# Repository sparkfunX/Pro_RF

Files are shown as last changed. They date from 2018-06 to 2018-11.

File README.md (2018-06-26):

SparkFun ProRF with RFM69/RFM95 LoRa
========================================

SparkFun ProRF

[*SparkX ProRF (SPX-14785)*](https://www.sparkfun.com/products/14785)

The Pro RF is the mind meld of a Pro Micro and a long-range RFM95W LoRa®-enabled radio. What you get is a very compact, easy to use Arduino with excellent point to point data transmission in the 915MHz ISM band. The Pro RF comes with a LiPo connector, a on-board LiPo charger, and a slide switch for On/Off. The board programs over a reinforced microB connector with a sleek reset button that fits nicely on the side of the board. We've even added our popular [Qwiic connector](https://www.sparkfun.com/qwiic) to the edge of the board making it incredibly fast to add sensors and actuators.

Thanks to the [Arduino LoRa library](https://github.com/sandeepmistry/arduino-LoRa), the RFM95W radio is an easy to use packet radio. But it doesn't stop at point-to-point packet radio because closing a few jumpers will give the Pro RF access to the DIO pins on the RFM95W which are necessary to operate in LoRaWAN mode, so you can use the Pro RF as a LoRaWAN node in a distributed sensor network such as [The Things Network](https://www.thethingsnetwork.org/).

The Pro RF also includes a power switch and 2-pin JST connector for powering from a lithium battery. With the power switch in the off position, the Pro RF will even charge the attached battery! 

And stop running out of ground pins! Every pin on the Pro RF is accompanied with a ground connection making buttons and LEDs super easy to connect. And in case your building something to be embedded into clothing or other physically harsh environment the antenna includes a stress relief hole to make sure your wire antenna survives.

Although a short (3 inch) wire antenna is sufficient for short distances (up to 1 mile line-of-sight), LoRa® is theoretically capable of covering extremely long distances (several miles) using the proper antenna. We've included the sketches we used for [range testing](https://cdn.sparkfun.com/assets/7/d/b/4/f/ProRF_RFM95.zip).

Checkout the [Pro Micro hookup guide](https://learn.sparkfun.com/tutorials/pro-micro--fio-v3-hookup-guide) as a general starting point for the Pro RF.

SparkFun labored with love to create this code. Feel like supporting open source hardware? 
Buy a [breakout board](https://www.sparkfun.com/products/14785) from SparkFun!

Repository Contents
-------------------

* **/Examples** - Example sketches showing how to setup the radio for maximuim range
* **/Hardware** - Eagle design files (.brd, .sch)

License Information
-------------------

This product is _**open source**_! 

If you have any questions or concerns on licensing, please contact techsupport@sparkfun.com.

Please use, reuse, and modify these files as you see fit. Please maintain attribution to SparkFun Electronics and release any derivative under the same license.

Distributed as-is; no warranty is given.

- Your friends at SparkFun.

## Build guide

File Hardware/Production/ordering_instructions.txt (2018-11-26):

panel size, 96x99mm
PCB thickness, 0.8mm
number of layers, 2
soldermask color, Red
silkscreen color, White
oz copper, 1oz
finish, HASL lead free
stencils, top
pcs per panel, 6

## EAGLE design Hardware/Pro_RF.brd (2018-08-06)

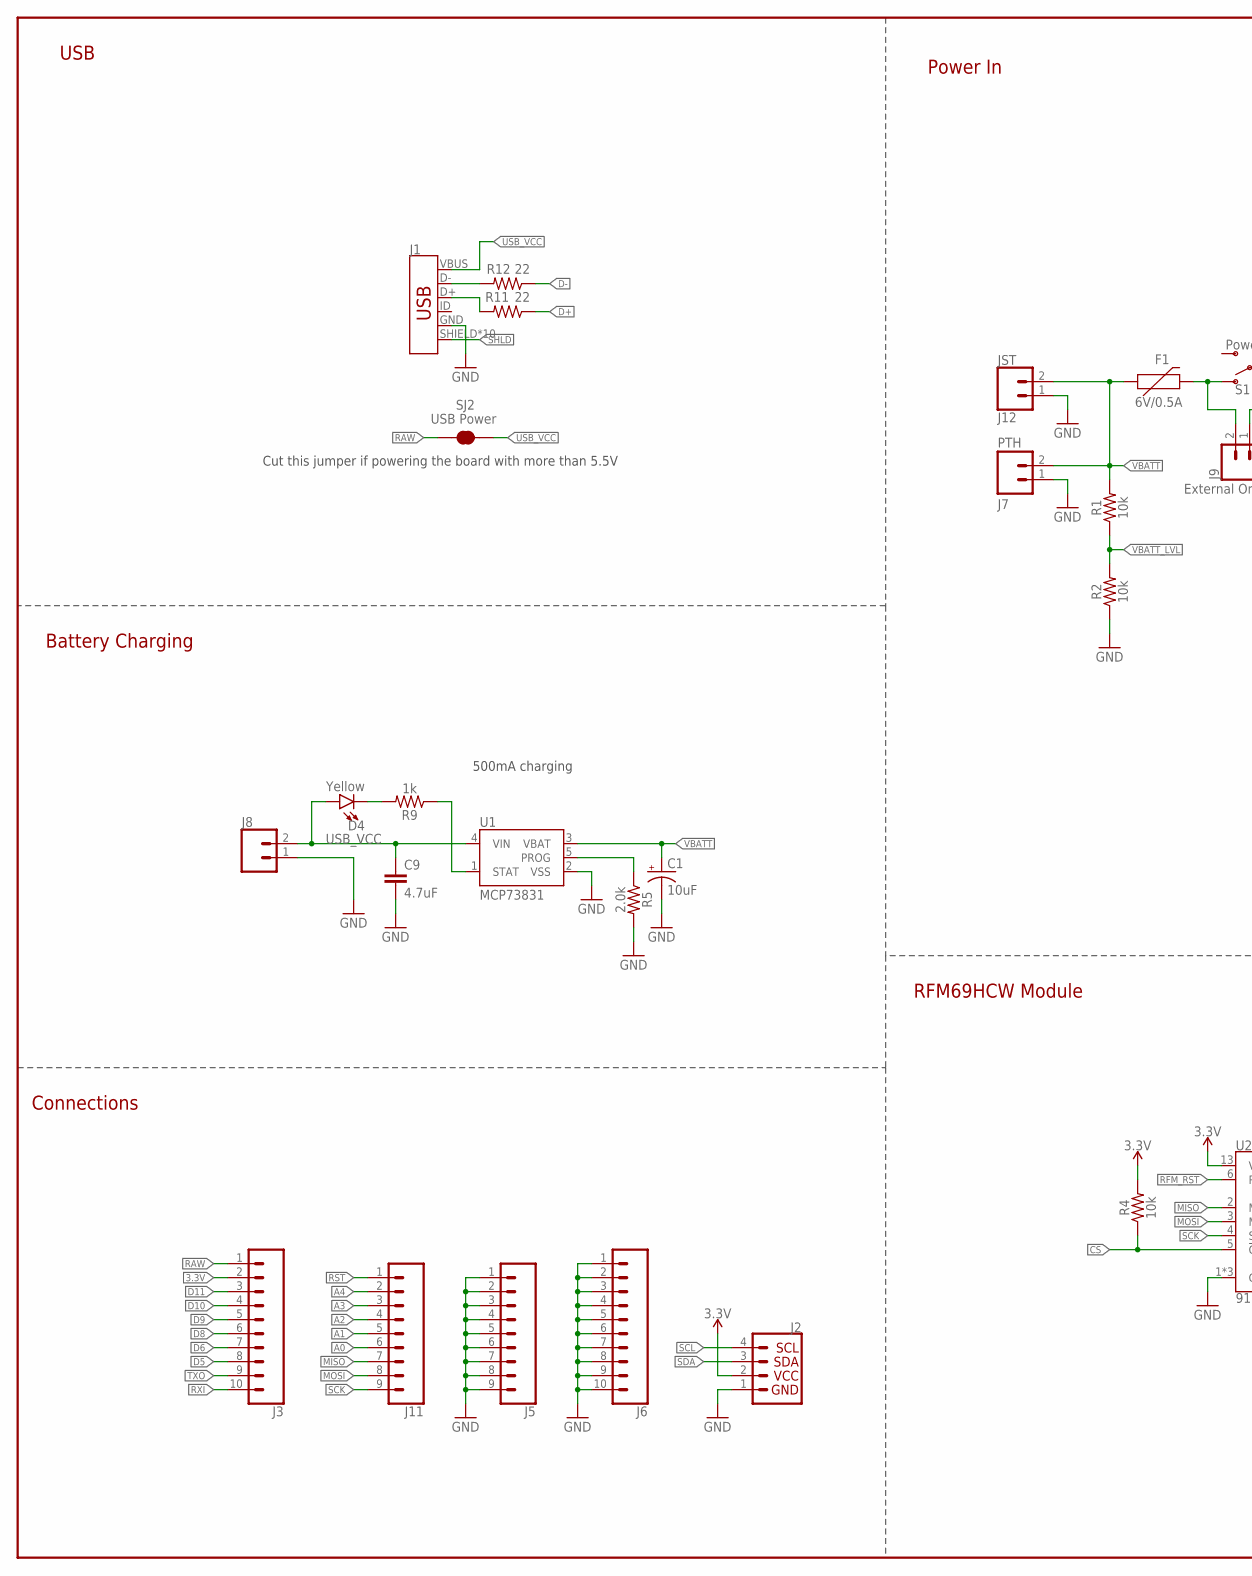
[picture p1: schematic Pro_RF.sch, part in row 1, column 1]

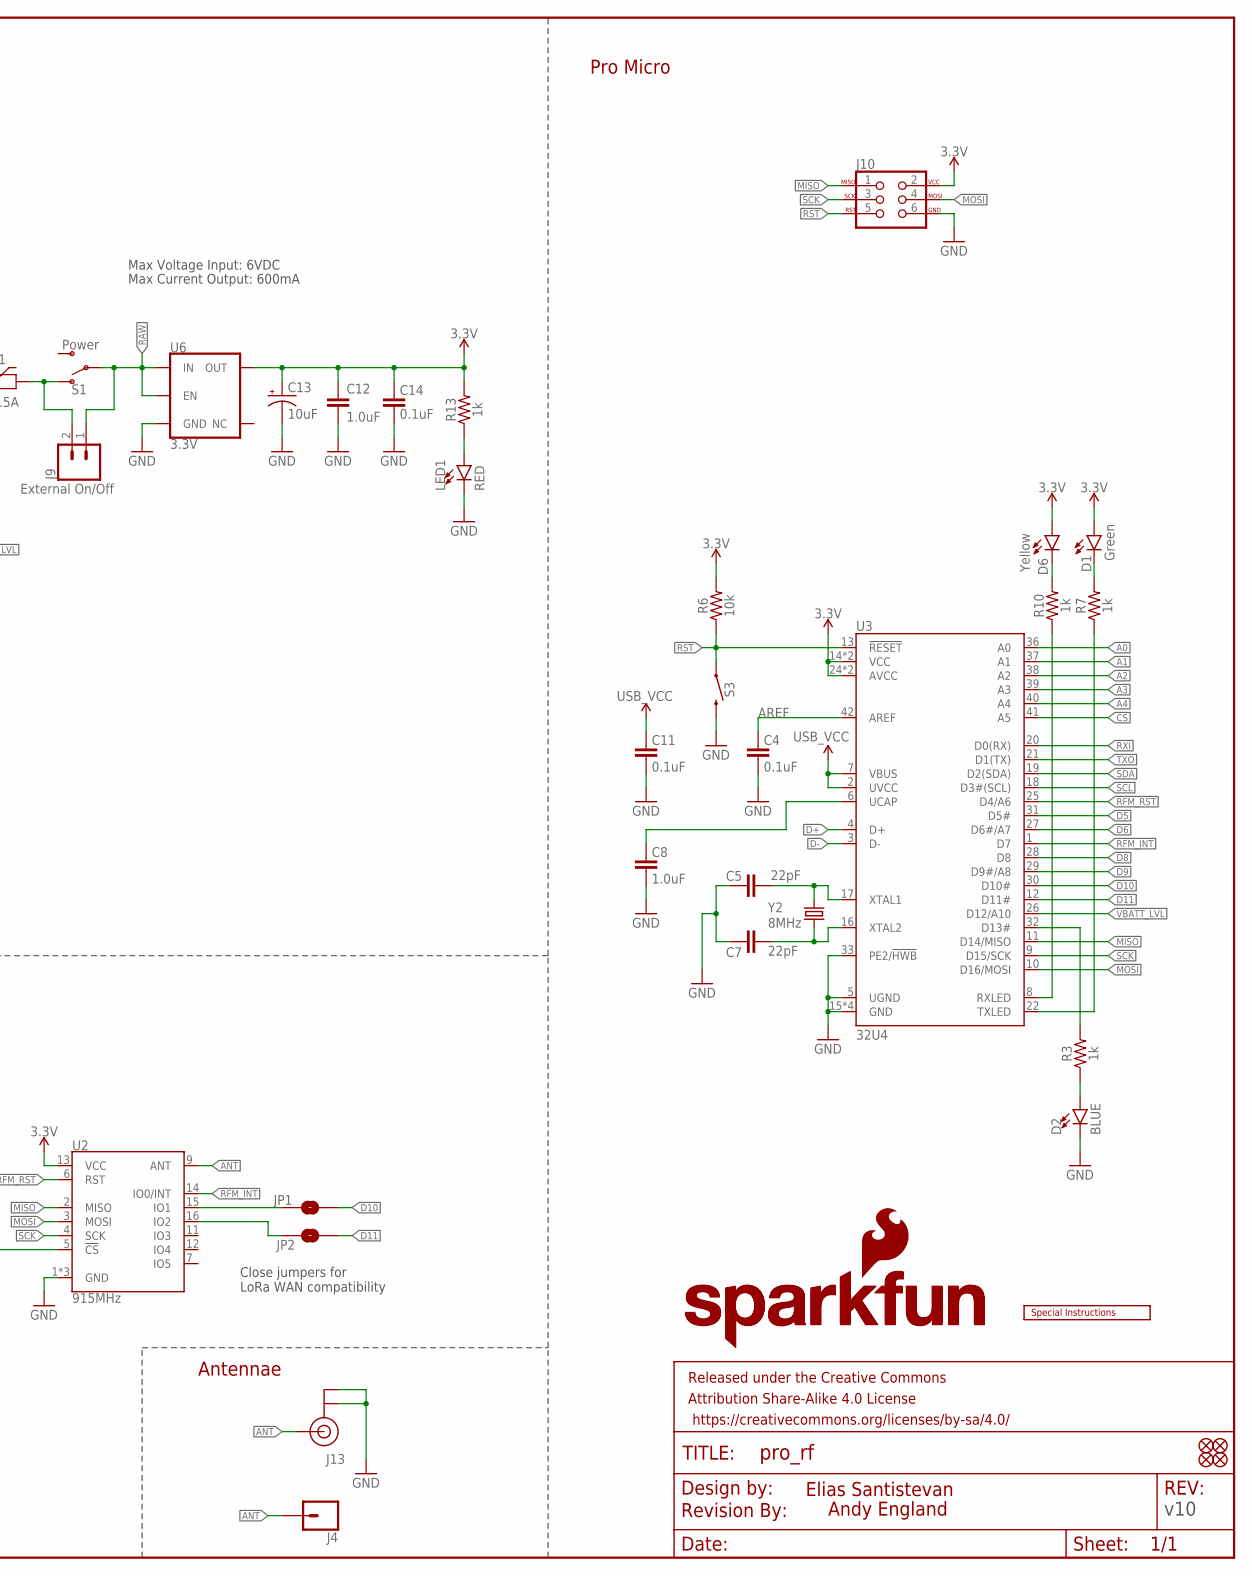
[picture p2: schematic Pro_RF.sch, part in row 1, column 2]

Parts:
C1, C13: 10uF; EIA3216
C4, C11, C14: 0.1uF; 0603
C5, C7: 22pF; 0603
C8, C12: 1.0uF; 0603
C9: 4.7uF; 0603
D1: Green; LED-0603
D2: BLUE; LED-0603
D4, D6: Yellow; LED-0603
F1: 6V/0.5A; 1206
FD1, FD2, FD3, FD4: FIDUCIAL1X2; FIDUCIAL-1X2
FRAME2: FRAME-LEDGER; CREATIVE_COMMONS
J1: USB_MICRO-B_HALF_PTH_MILL; USB-MICROB-PTH-MILL
J2: QWIIC_CONNECTORJS-1MM; 1X04_1MM_RA
J3, J6: CONN_10NO_SILK_PTH_FEMALE; 1X10_NO_SILK
J4: CONN_01PTH_NO_SILK_YES_STOP; 1X01_NO_SILK
J5, J11: CONN_09NO_SILK; 1X09_NO_SILK
J7: PTH; 1X02_NO_SILK
J8: CONN_021X02_NO_SILK; 1X02_NO_SILK
J9: External On/Off; 1X02_NO_SILK
J10: AVR_SPI_PROG_3X2TESTPOINTS; 2X3_TEST_POINTS
J12: JST; JST-2-SMD
J13: U.FL
JP1, JP2: JUMPER-SMT_2_NO_SILK; SMT-JUMPER_2_NO_SILK
LED1: RED; LED-0603
LOGO1: REVISION
LOGO2: SFE_LOGO_NAME.1_INCH; SFE_LOGO_NAME_.1
LOGO3: SFE_LOGO_NAME_FLAME.1_INCH; SFE_LOGO_NAME_FLAME_.1
R1, R2, R4, R6: 10k; 0603
R3, R7, R9, R10, R13: 1k; 0603
R5: 2.0k; 0603
R11, R12: 22; 0603
S1: Power; SWITCH_SPST_SMD_A
S3: MOMENTARY-SWITCH-SPST-SMD-RIGHT-ANGLE; TACTILE_SWITCH_SMD_RIGHT_ANGLE
SJ2: USB Power; SMT-JUMPER_2_NC_TRACE_SILK
U1: MCP73831; SOT23-5
U2: 915MHz; RFM69HCW-XXXS2
U3: 32U4; QFN-44-NOPAD
U6: 3.3V; SOT23-5
U$26: SPECIAL_INSTRUCTIONS-ORDERING; ORDERING_INSTRUCTIONS
Y2: 8MHz; CRYSTAL-SMD-5X3.2-4PAD

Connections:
3.3V: C12.1, C13.+, C14.2, D1.A, D6.A, J2.2, J3.2, J10.2, R4.2, R6.2, R13.2, U2.13 (VCC), U3.14 (VCC), U3.24 (AVCC), U3.34 (VCC), U3.44 (AVCC), U6.5 (OUT)
!CS: R4.1, U2.5 (!CS), U3.41 (A5)
!RST: J10.5, J11.1, R6.1, S3.1, U3.13 (!RESET)
A0: J11.6, U3.36 (A0)
A1: J11.5, U3.37 (A1)
A2: J11.4, U3.38 (A2)
A3: J11.3, U3.39 (A3)
A4: J11.2, U3.40 (A4)
ANT: J4.1, J13.FEED (SIGNAL), U2.9 (ANT)
AREF: C4.2, U3.42 (AREF)
CHARGE_STAT: R9.1, U1.1 (STAT)
D5: J3.8, U3.31 (D5#)
D6: J3.7, U3.27 (D6#/A7)
D8: J3.6, U3.28 (D8)
D9: J3.5, U3.29 (D9#/A8)
D10: J3.4, JP1.2, U3.30 (D10#)
D11: J3.3, JP2.2, U3.12 (D11#)
D+: R11.1, U3.4 (D+)
D-: R12.1, U3.3 (D-)
GND: C1.-, C4.1, C5.2, C7.2, C8.1, C9.2, C11.1, C12.2, C13.-, C14.1, D2.C, J1.GND, J2.1, J5.1, J5.2, J5.3, J5.4, J5.5, J5.6, J5.7, J5.8, J5.9, J6.1, J6.2, J6.3, J6.4, J6.5, J6.6, J6.7, J6.8, J6.9, J6.10, J7.1, J8.1, J10.6, J12.1 (2), J13.1 (GND), J13.2 (GND), LED1.C, R2.1, R5.2, S3.2, U1.2 (VSS), U2.1 (GND), U2.8 (GND), U2.10 (GND), U3.5 (UGND), U3.15 (GND), U3.23 (GND), U3.33 (PE2/!HWB), U3.35 (GND), U3.43 (GND), U6.2 (GND)
MISO: J10.1, J11.7, U2.2 (MISO), U3.11 (D14/MISO)
MOSI: J10.4, J11.8, U2.3 (MOSI), U3.10 (D16/MOSI)
unnamed: D6.C, R10.2
unnamed: D1.C, R7.2
unnamed: D2.A, R3.1
unnamed: C5.1, U3.17 (XTAL1), Y2.3 (2)
unnamed: J1.D+, R11.2
unnamed: C7.1, U3.16 (XTAL2), Y2.1
unnamed: D4.C, R9.2
unnamed: F1.2, J9.2, S1.1 (O)
unnamed: R5.1, U1.5 (PROG)
unnamed: J1.D-, R12.2
unnamed: LED1.A, R13.1
RAW: J3.1, J9.1, S1.2, SJ2.1, U6.1 (IN), U6.3 (EN)
RFM_INT: U2.14 (IO0/INT), U3.1 (D7)
RFM_IO1: JP1.1, U2.15 (IO1)
RFM_IO2: JP2.1, U2.16 (IO2)
RFM_RST: U2.6 (RST), U3.25 (D4/A6)
RXI: J3.10, U3.20 (D0(RX))
RXLED: R10.1, U3.8 (RXLED)
SCK: J10.3, J11.9, U2.4 (SCK), U3.9 (D15/SCK)
SCL: J2.4, U3.18 (D3#(SCL))
SDA: J2.3, U3.19 (D2(SDA))
SHLD: J1.SHIELD, J1.SHIELD2 (SHIELD), J1.SHIELD3 (SHIELD), J1.SHIELD4 (SHIELD), J1.SHIELD5 (SHIELD), J1.SHIELD6 (SHIELD), J1.SHIELD7 (SHIELD), J1.SHIELD8 (SHIELD), J1.SHIELD9 (SHIELD), J1.SHIELD10 (SHIELD)
STAT: R3.2, U3.32 (D13#)
TXLED: R7.1, U3.22 (TXLED)
TXO: J3.9, U3.21 (D1(TX))
UCAP: C8.2, U3.6 (UCAP)
USB_VCC: C9.1, C11.2, D4.A, J1.VBUS, J8.2, SJ2.2, U1.4 (VIN), U3.2 (UVCC), U3.7 (VBUS)
VBATT: C1.+, F1.1, J7.2, J12.2 (1), R1.2, U1.3 (VBAT)
VBATT_LVL: R1.1, R2.2, U3.26 (D12/A10)

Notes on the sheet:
Max Voltage Input: 6VDC
Max Current Output: 600mA
Cut this jumper if powering the board with more than 5.5V
500mA charging
Close jumpers for LoRa WAN compatibility
Battery Charging
Power In
Pro Micro
RFM69HCW Module
v10
Andy England
Connections
Elias Santistevan
USB
Antennae

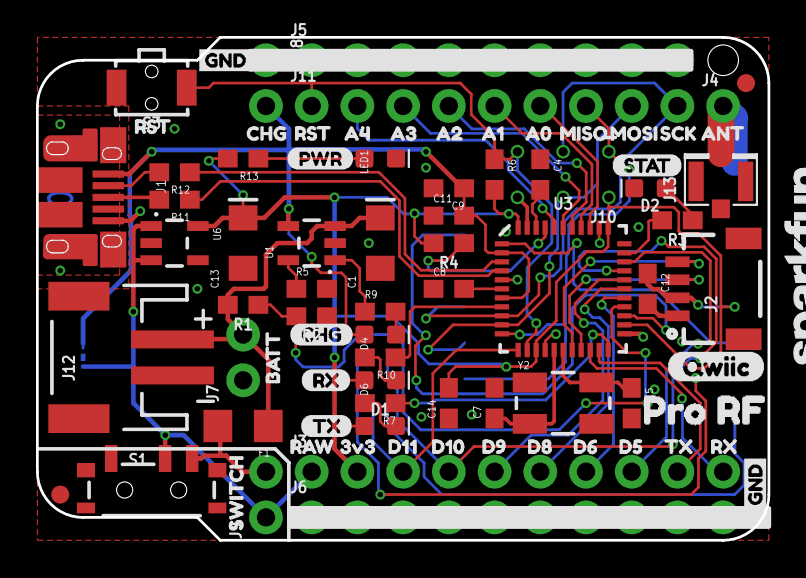
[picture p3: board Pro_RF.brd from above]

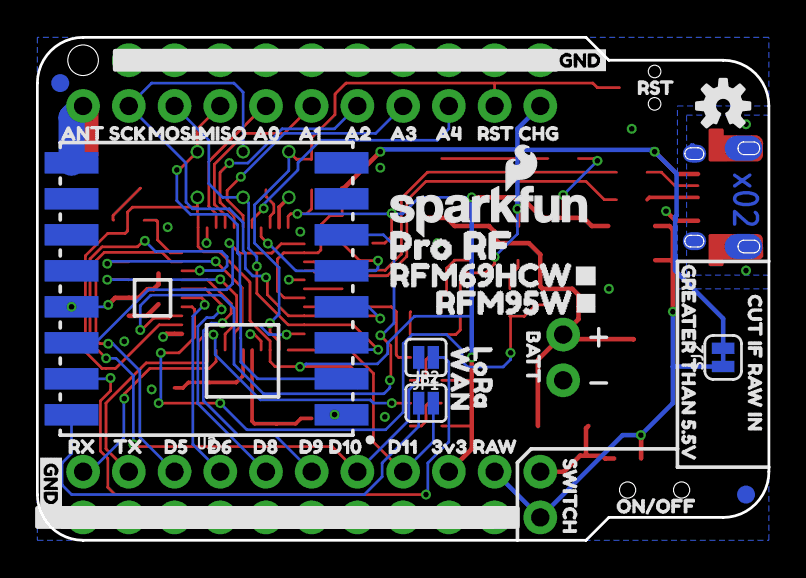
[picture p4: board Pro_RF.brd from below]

Board: 2 copper layers, 40.6 x 27.9 mm, 128 parts (42 on the bottom side), 51 nets.

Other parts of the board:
U$1, U$31: PRO_RF0
U$3, U$42: A43
U$4, U$43: A34
U$5, U$44: A25
U$6, U$45: A16
U$7, U$46: A07
U$8, U$47: MISO8
U$9, U$48: MOSI9
U$10, U$49: SCK10
U$11, U$50: ANT11
U$12, U$17, U$38, U$62: GND0
U$13, U$28, U$36, U$41: RST2
U$14, U$40, U$65: CHG1
U$15, U$16: D90
U$18, U$58: D615
U$19, U$73: RX2
U$20, U$56: D817
U$21, U$68: D100
U$22, U$54: D1119
U$23, U$53: 3V320
U$24, U$52: RAW21
U$25: LORA0
U$27, U$37: SWITCH23
U$29, U$32: BATT25
U$33: CUT_IF_RAW_IN0
U$34: GREATER_THAN_5#5V1
U$35: WAN1
U$39: ON#OFF0
U$51: OSHW-LOGO-S
U$55, U$74: D514
U$57, U$69: TX3
U$59: RFM69HCW#1
U$60: RFM95W#0
U$63: PWR-()-03
U$66: QWIIC-()-04
U$70: TX6
U$71: STAT5
U$72: RX7

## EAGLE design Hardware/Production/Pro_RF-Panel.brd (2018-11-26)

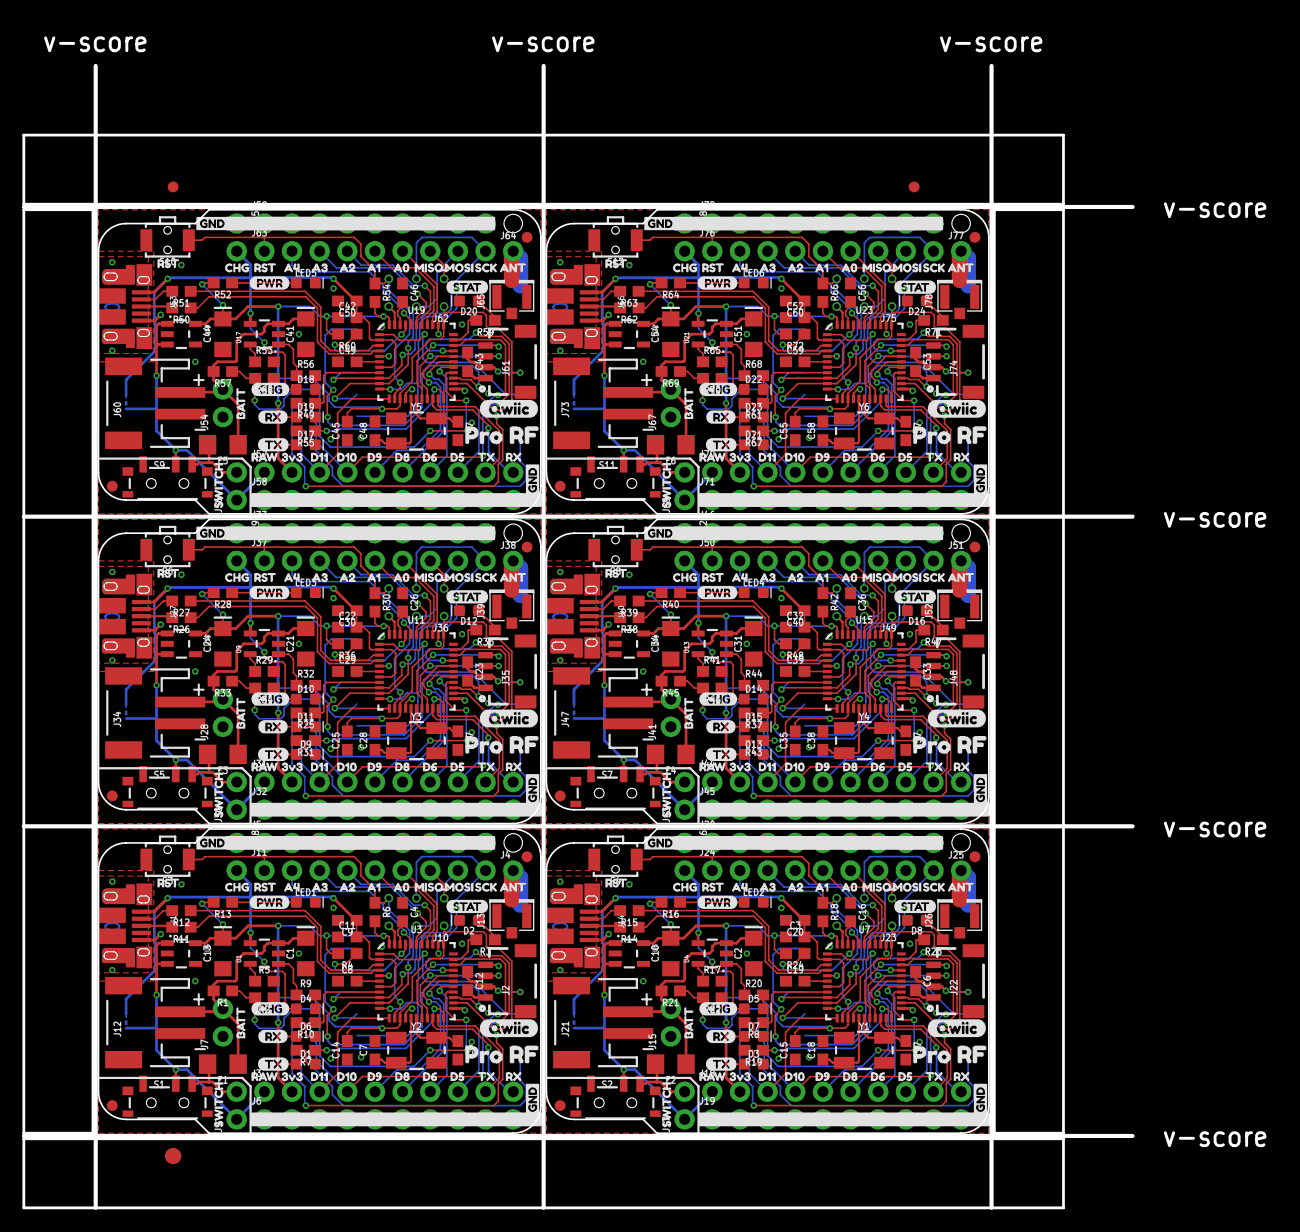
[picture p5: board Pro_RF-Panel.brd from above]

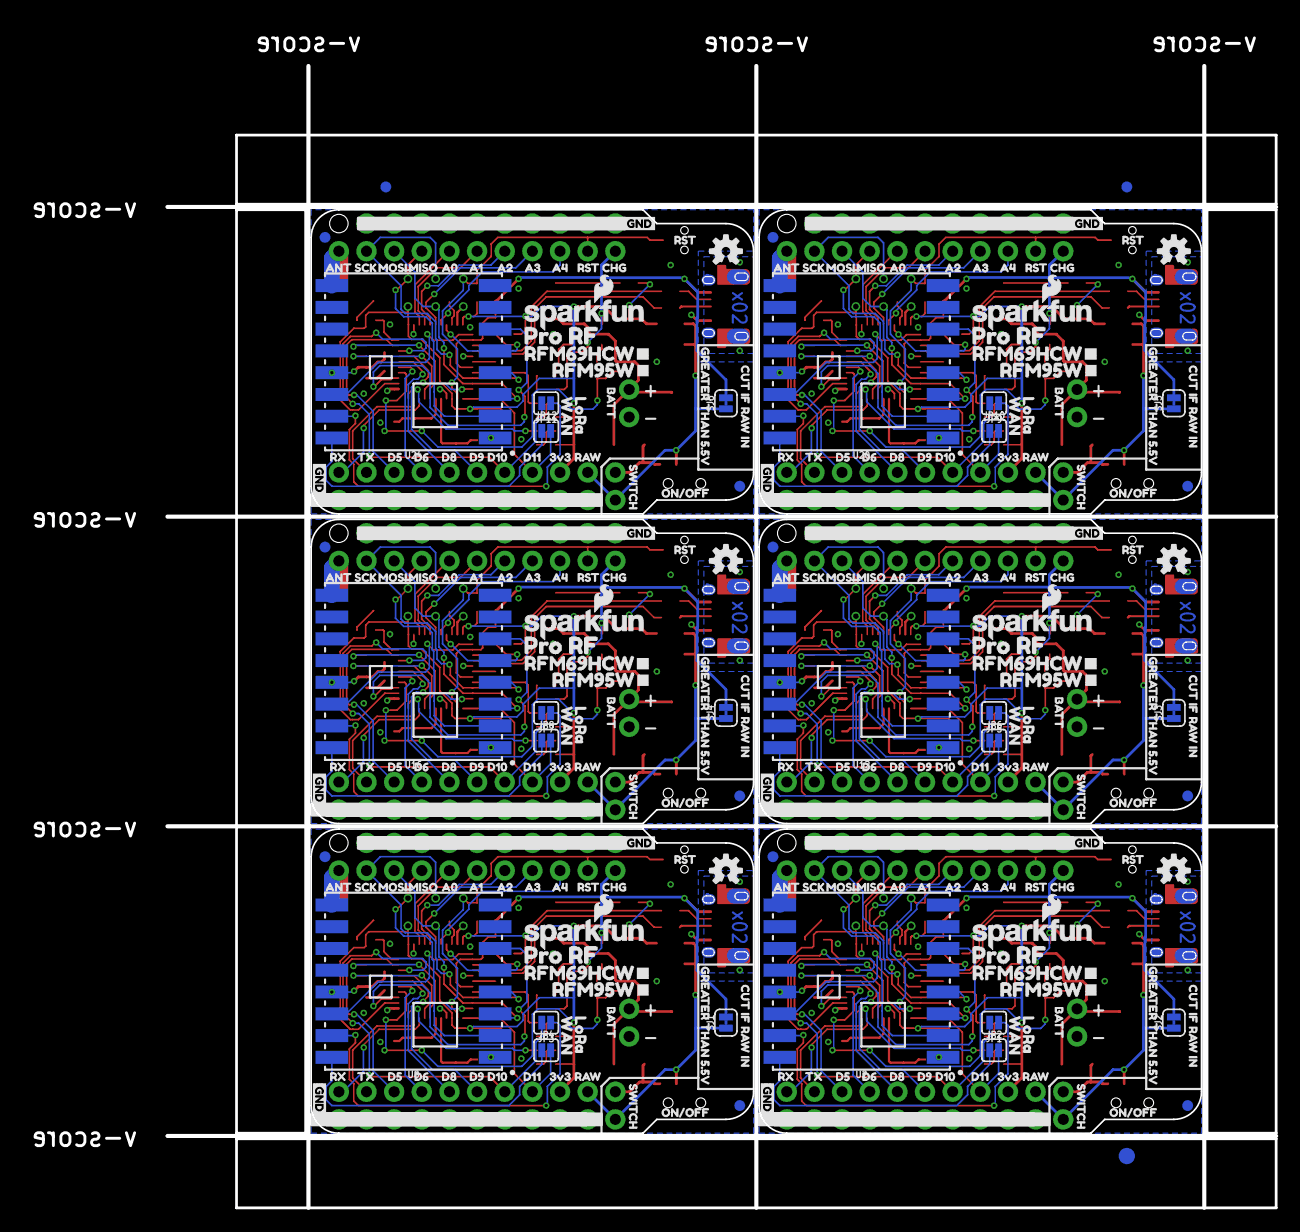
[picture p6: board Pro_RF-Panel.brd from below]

Board: 2 copper layers, 101.9 x 104.9 mm, 750 parts (255 on the bottom side), 306 nets.

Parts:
C1, C2, C10, C13, C21, C24, C31, C34, C41, C44, C51, C54: 10uF; EIA3216
C3, C4, C11, C14, C15, C16, C22, C25, C26, C32, C35, C36, C42, C45, C46, C52, C55, C56: 0.1uF; 0603
C5, C7, C17, C18, C27, C28, C37, C38, C47, C48, C57, C58: 22pF; 0603
C6, C8, C12, C19, C23, C29, C33, C39, C43, C49, C53, C59: 1.0uF; 0603
C9, C20, C30, C40, C50, C60: 4.7uF; 0603
D1, D3, D9, D13, D17, D21: Green; LED-0603
D2, D8, D12, D16, D20, D24: BLUE; LED-0603
D4, D5, D6, D7, D10, D11, D14, D15, D18, D19, D22, D23: Yellow; LED-0603
E$1, E$2, E$3, E$4: FIDUCIAL-1X2
E$5, E$6: FIDUCIAL-1.5X3
F1, F2, F3, F4, F5, F6: 6V/0.5A; 1206
FD1, FD2, FD3, FD4, FD5, FD6, FD7, FD8, FD9, FD10, FD11, FD12, FD13, FD14, FD15, FD16, FD17, FD18, FD19, FD20, FD21, FD22, FD23, FD24: FIDUCIAL1X2; FIDUCIAL-1X2
J1, J14, J27, J40, J53, J66: USB-MICROB-PTH-MILL
J2, J22, J35, J48, J61, J74: 1X04_1MM_RA
J3, J6, J18, J19, J31, J32, J44, J45, J57, J58, J70, J71: 1X10_NO_SILK
J4, J25, J38, J51, J64, J77: 1X01_NO_SILK
J5, J11, J20, J24, J33, J37, J46, J50, J59, J63, J72, J76: 1X09_NO_SILK
J7, J15, J28, J41, J54, J67: PTH; 1X02_NO_SILK
J8, J16, J29, J42, J55, J68: 1X02_NO_SILK
J9, J17, J30, J43, J56, J69: External On/Off; 1X02_NO_SILK
J10, J23, J36, J49, J62, J75: AVR_SPI_PROG_3X2TESTPOINTS; 2X3_TEST_POINTS
J12, J21, J34, J47, J60, J73: JST; JST-2-SMD
J13, J26, J39, J52, J65, J78: U.FL
JP1, JP2, JP3, JP4, JP5, JP6, JP7, JP8, JP9, JP10, JP11, JP12: SMT-JUMPER_2_NO_SILK
LED1, LED2, LED3, LED4, LED5, LED6: RED; LED-0603
LOGO1, LOGO2, LOGO3, LOGO4, LOGO5, LOGO6: SFE_LOGO_NAME_FLAME.1_INCH; SFE_LOGO_NAME_FLAME_.1
R1, R2, R4, R6, R18, R21, R22, R24, R30, R33, R34, R36, R42, R45, R46, R48, R54, R57, R58, R60, R66, R69, R70, R72: 10k; 0603
R3, R7, R8, R9, R10, R13, R16, R19, R20, R23, R25, R28, R31, R32, R35, R37, R40, R43, R44, R47, R49, R52, R55, R56, R59, R61, R64, R67, R68, R71: 1k; 0603
R5, R17, R29, R41, R53, R65: 2.0k; 0603
R11, R12, R14, R15, R26, R27, R38, R39, R50, R51, R62, R63: 22; 0603
S1, S2, S5, S7, S9, S11: Power; SWITCH_SPST_SMD_A
S3, S4, S6, S8, S10, S12: TACTILE_SWITCH_SMD_RIGHT_ANGLE
SJ1, SJ2, SJ3, SJ4, SJ5, SJ6: USB Power; SMT-JUMPER_2_NC_TRACE_SILK
U1, U4, U9, U13, U17, U21: MCP73831; SOT23-5
U2, U8, U12, U16, U20, U24: 915MHz; RFM69HCW-XXXS2
U3, U7, U11, U15, U19, U23: 32U4; QFN-44-NOPAD
U5, U6, U10, U14, U18, U22: 3.3V; SOT23-5
U$1, U$2, U$31, U$90, U$137, U$158, U$205, U$226, U$273, U$294, U$341, U$362: PRO_RF0
U$3, U$26, U$42, U$100, U$138, U$168, U$206, U$236, U$274, U$304, U$342, U$372: A43
U$4, U$30, U$43, U$101, U$139, U$169, U$207, U$237, U$275, U$305, U$343, U$373: A34
U$5, U$44, U$61, U$102, U$140, U$170, U$208, U$238, U$276, U$306, U$344, U$374: A25
U$6, U$45, U$64, U$103, U$141, U$171, U$209, U$239, U$277, U$307, U$345, U$375: A16
U$7, U$46, U$67, U$104, U$142, U$172, U$210, U$240, U$278, U$308, U$346, U$376: A07
U$8, U$47, U$75, U$105, U$143, U$173, U$211, U$241, U$279, U$309, U$347, U$377: MISO8
U$9, U$48, U$76, U$106, U$144, U$174, U$212, U$242, U$280, U$310, U$348, U$378: MOSI9
U$10, U$49, U$77, U$107, U$145, U$175, U$213, U$243, U$281, U$311, U$349, U$379: SCK10
U$11, U$50, U$78, U$108, U$146, U$176, U$214, U$244, U$282, U$312, U$350, U$380: ANT11
U$12, U$17, U$38, U$62, U$79, U$96, U$115, U$130, U$147, U$164, U$183, U$198, U$215, U$232, U$251, U$266, U$283, U$300, U$319, U$334, U$351, U$368, U$387, U$402: GND0
U$13, U$28, U$36, U$41, U$80, U$88, U$94, U$99, U$148, U$156, U$162, U$167, U$216, U$224, U$230, U$235, U$284, U$292, U$298, U$303, U$352, U$360, U$366, U$371: RST2
U$14, U$40, U$65, U$81, U$98, U$123, U$149, U$166, U$191, U$217, U$234, U$259, U$285, U$302, U$327, U$353, U$370, U$395: CHG1
U$15, U$16, U$128, U$129, U$196, U$197, U$264, U$265, U$332, U$333, U$400, U$401: D90
U$18, U$58, U$82, U$114, U$150, U$182, U$218, U$250, U$286, U$318, U$354, U$386: D615
U$19, U$73, U$122, U$131, U$190, U$199, U$258, U$267, U$326, U$335, U$394, U$403: RX2
U$20, U$56, U$83, U$113, U$151, U$181, U$219, U$249, U$287, U$317, U$355, U$385: D817
U$21, U$68, U$124, U$125, U$192, U$193, U$260, U$261, U$328, U$329, U$396, U$397: D100
U$22, U$54, U$84, U$112, U$152, U$180, U$220, U$248, U$288, U$316, U$356, U$384: D1119
U$23, U$53, U$85, U$111, U$153, U$179, U$221, U$247, U$289, U$315, U$357, U$383: 3V320
U$24, U$52, U$86, U$110, U$154, U$178, U$222, U$246, U$290, U$314, U$358, U$382: RAW21
U$25, U$135, U$203, U$271, U$339, U$407: LORA0
U$27, U$37, U$87, U$95, U$155, U$163, U$223, U$231, U$291, U$299, U$359, U$367: SWITCH23
U$29, U$32, U$89, U$91, U$157, U$159, U$225, U$227, U$293, U$295, U$361, U$363: BATT25
U$33, U$92, U$160, U$228, U$296, U$364: CUT_IF_RAW_IN0
U$34, U$93, U$161, U$229, U$297, U$365: GREATER_THAN_5#5V1
U$35, U$136, U$204, U$272, U$340, U$408: WAN1
U$39, U$97, U$165, U$233, U$301, U$369: ON#OFF0
U$51, U$109, U$177, U$245, U$313, U$381: OSHW-LOGO-S
U$55, U$74, U$126, U$127, U$194, U$195, U$262, U$263, U$330, U$331, U$398, U$399: D514
U$57, U$69, U$118, U$132, U$186, U$200, U$254, U$268, U$322, U$336, U$390, U$404: TX3
U$59, U$133, U$201, U$269, U$337, U$405: RFM69HCW#1
U$60, U$134, U$202, U$270, U$338, U$406: RFM95W#0
U$63, U$116, U$184, U$252, U$320, U$388: PWR-()-03
U$66, U$117, U$185, U$253, U$321, U$389: QWIIC-()-04
U$70, U$119, U$187, U$255, U$323, U$391: TX6
U$71, U$120, U$188, U$256, U$324, U$392: STAT5
U$72, U$121, U$189, U$257, U$325, U$393: RX7
Y1, Y2, Y3, Y4, Y5, Y6: 8MHz; CRYSTAL-SMD-5X3.2-4PAD

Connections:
3.3V: C12.1, C13.+, C14.2, D1.A, D6.A, J2.2, J3.2, J10.2, R4.2, R6.2, R13.2, U2.13, U3.14, U3.24, U3.34, U3.44, U6.5
3.3V1: C6.1, C10.+, C15.2, D3.A, D7.A, J18.2, J22.2, J23.2, R16.2, R18.2, R24.2, U5.5, U7.14, U7.24, U7.34, U7.44, U8.13
3.3V2: C23.1, C24.+, C25.2, D9.A, D11.A, J31.2, J35.2, J36.2, R28.2, R30.2, R36.2, U10.5, U11.14, U11.24, U11.34, U11.44, U12.13
3.3V3: C33.1, C34.+, C35.2, D13.A, D15.A, J44.2, J48.2, J49.2, R40.2, R42.2, R48.2, U14.5, U15.14, U15.24, U15.34, U15.44, U16.13
3.3V4: C43.1, C44.+, C45.2, D17.A, D19.A, J57.2, J61.2, J62.2, R52.2, R54.2, R60.2, U18.5, U19.14, U19.24, U19.34, U19.44, U20.13
3.3V5: C53.1, C54.+, C55.2, D21.A, D23.A, J70.2, J74.2, J75.2, R64.2, R66.2, R72.2, U22.5, U23.14, U23.24, U23.34, U23.44, U24.13
!CS: R4.1, U2.5, U3.41
!CS1: R24.1, U7.41, U8.5
!CS2: R36.1, U11.41, U12.5
!CS3: R48.1, U15.41, U16.5
!CS4: R60.1, U19.41, U20.5
!CS5: R72.1, U23.41, U24.5
!RST: J10.5, J11.1, R6.1, S3.1, U3.13
!RST1: J23.5, J24.1, R18.1, S4.1, U7.13
!RST2: J36.5, J37.1, R30.1, S6.1, U11.13
!RST3: J49.5, J50.1, R42.1, S8.1, U15.13
!RST4: J62.5, J63.1, R54.1, S10.1, U19.13
!RST5: J75.5, J76.1, R66.1, S12.1, U23.13
A0: J11.6, U3.36
A1: J11.5, U3.37
A2: J11.4, U3.38
A3: J11.3, U3.39
A4: J11.2, U3.40
A5: J24.6, U7.36
A6: J24.5, U7.37
A7: J24.4, U7.38
A8: J24.3, U7.39
A9: J24.2, U7.40
A10: J37.6, U11.36
A11: J37.5, U11.37
A12: J37.4, U11.38
A13: J37.3, U11.39
A14: J37.2, U11.40
A15: J50.6, U15.36
A16: J50.5, U15.37
A17: J50.4, U15.38
A18: J50.3, U15.39
A19: J50.2, U15.40
A20: J63.6, U19.36
A21: J63.5, U19.37
A22: J63.4, U19.38
A23: J63.3, U19.39
A24: J63.2, U19.40
A25: J76.6, U23.36
A26: J76.5, U23.37
A27: J76.4, U23.38
A28: J76.3, U23.39
A29: J76.2, U23.40
ANT: J4.1, J13.FEED, U2.9
ANT1: J25.1, J26.FEED, U8.9
ANT2: J38.1, J39.FEED, U12.9
ANT3: J51.1, J52.FEED, U16.9
ANT4: J64.1, J65.FEED, U20.9
ANT5: J77.1, J78.FEED, U24.9
AREF: C4.2, U3.42
AREF1: C16.2, U7.42
AREF2: C26.2, U11.42
AREF3: C36.2, U15.42
AREF4: C46.2, U19.42
AREF5: C56.2, U23.42
CHARGE_STAT: R9.1, U1.1
CHARGE_STAT1: R20.1, U4.1
CHARGE_STAT2: R32.1, U9.1
CHARGE_STAT3: R44.1, U13.1
CHARGE_STAT4: R56.1, U17.1
CHARGE_STAT5: R68.1, U21.1
D1: J18.8, U7.31
D2: J18.7, U7.27
D3: J18.6, U7.28
D4: J18.4, JP3.2, U7.30
D5: J3.8, U3.31
D6: J3.7, U3.27
D7: J18.5, U7.29
D8: J3.6, U3.28
D9: J3.5, U3.29
D10: J3.4, JP1.2, U3.30
D11: J3.3, JP2.2, U3.12
D12: J18.3, JP4.2, U7.12
D13: J31.8, U11.31
D14: J31.7, U11.27
D15: J31.6, U11.28
D16: J31.4, JP5.2, U11.30
D17: J31.5, U11.29
D18: J31.3, JP6.2, U11.12
D19: J44.8, U15.31
D20: J44.7, U15.27
D21: J44.6, U15.28
D22: J44.4, JP7.2, U15.30
D23: J44.5, U15.29
D24: J44.3, JP8.2, U15.12
D25: J57.8, U19.31
D26: J57.7, U19.27
D27: J57.6, U19.28
D28: J57.4, JP9.2, U19.30
D29: J57.5, U19.29
D30: J57.3, JP10.2, U19.12
D31: J70.8, U23.31
D32: J70.7, U23.27
D33: J70.6, U23.28
D34: J70.4, JP11.2, U23.30
D35: J70.5, U23.29
D36: J70.3, JP12.2, U23.12
D+: R11.1, U3.4
D+1: R14.1, U7.4
D+2: R26.1, U11.4
D+3: R38.1, U15.4
D+4: R50.1, U19.4
D+5: R62.1, U23.4
D-: R12.1, U3.3
D-1: R15.1, U7.3
D-2: R27.1, U11.3
D-3: R39.1, U15.3
D-4: R51.1, U19.3
D-5: R63.1, U23.3
GND: C1.-, C4.1, C5.2, C7.2, C8.1, C9.2, C11.1, C12.2, C13.-, C14.1, D2.C, J1.GND, J2.1, J5.1, J5.2, J5.3, J5.4, J5.5, J5.6, J5.7, J5.8, J5.9, J6.1, J6.2, J6.3, J6.4, J6.5, J6.6, J6.7, J6.8, J6.9, J6.10, J7.1, J8.1, J10.6, J12.1, J13.1, J13.2, LED1.C, R2.1, R5.2, S3.2, U1.2, U2.1, U2.8, U2.10, U3.5, U3.15, U3.23, U3.33, U3.35, U3.43, U6.2
GND1: C2.-, C3.1, C6.2, C10.-, C15.1, C16.1, C17.2, C18.2, C19.1, C20.2, D8.C, J14.GND, J15.1, J16.1, J19.1, J19.2, J19.3, J19.4, J19.5, J19.6, J19.7, J19.8, J19.9, J19.10, J20.1, J20.2, J20.3, J20.4, J20.5, J20.6, J20.7, J20.8, J20.9, J21.1, J22.1, J23.6, J26.1, J26.2, LED2.C, R17.2, R22.1, S4.2, U4.2, U5.2, U7.5, U7.15, U7.23, U7.33, U7.35, U7.43, U8.1, U8.8, U8.10
GND2: C21.-, C22.1, C23.2, C24.-, C25.1, C26.1, C27.2, C28.2, C29.1, C30.2, D12.C, J27.GND, J28.1, J29.1, J32.1, J32.2, J32.3, J32.4, J32.5, J32.6, J32.7, J32.8, J32.9, J32.10, J33.1, J33.2, J33.3, J33.4, J33.5, J33.6, J33.7, J33.8, J33.9, J34.1, J35.1, J36.6, J39.1, J39.2, LED3.C, R29.2, R34.1, S6.2, U9.2, U10.2, U11.5, U11.15, U11.23, U11.33, U11.35, U11.43, U12.1, U12.8, U12.10
GND3: C31.-, C32.1, C33.2, C34.-, C35.1, C36.1, C37.2, C38.2, C39.1, C40.2, D16.C, J40.GND, J41.1, J42.1, J45.1, J45.2, J45.3, J45.4, J45.5, J45.6, J45.7, J45.8, J45.9, J45.10, J46.1, J46.2, J46.3, J46.4, J46.5, J46.6, J46.7, J46.8, J46.9, J47.1, J48.1, J49.6, J52.1, J52.2, LED4.C, R41.2, R46.1, S8.2, U13.2, U14.2, U15.5, U15.15, U15.23, U15.33, U15.35, U15.43, U16.1, U16.8, U16.10
GND4: C41.-, C42.1, C43.2, C44.-, C45.1, C46.1, C47.2, C48.2, C49.1, C50.2, D20.C, J53.GND, J54.1, J55.1, J58.1, J58.2, J58.3, J58.4, J58.5, J58.6, J58.7, J58.8, J58.9, J58.10, J59.1, J59.2, J59.3, J59.4, J59.5, J59.6, J59.7, J59.8, J59.9, J60.1, J61.1, J62.6, J65.1, J65.2, LED5.C, R53.2, R58.1, S10.2, U17.2, U18.2, U19.5, U19.15, U19.23, U19.33, U19.35, U19.43, U20.1, U20.8, U20.10
GND5: C51.-, C52.1, C53.2, C54.-, C55.1, C56.1, C57.2, C58.2, C59.1, C60.2, D24.C, J66.GND, J67.1, J68.1, J71.1, J71.2, J71.3, J71.4, J71.5, J71.6, J71.7, J71.8, J71.9, J71.10, J72.1, J72.2, J72.3, J72.4, J72.5, J72.6, J72.7, J72.8, J72.9, J73.1, J74.1, J75.6, J78.1, J78.2, LED6.C, R65.2, R70.1, S12.2, U21.2, U22.2, U23.5, U23.15, U23.23, U23.33, U23.35, U23.43, U24.1, U24.8, U24.10
MISO: J10.1, J11.7, U2.2, U3.11
MISO1: J23.1, J24.7, U7.11, U8.2
MISO2: J36.1, J37.7, U11.11, U12.2
MISO3: J49.1, J50.7, U15.11, U16.2
MISO4: J62.1, J63.7, U19.11, U20.2
MISO5: J75.1, J76.7, U23.11, U24.2
MOSI: J10.4, J11.8, U2.3, U3.10
MOSI1: J23.4, J24.8, U7.10, U8.3
MOSI2: J36.4, J37.8, U11.10, U12.3
MOSI3: J49.4, J50.8, U15.10, U16.3
MOSI4: J62.4, J63.8, U19.10, U20.3
MOSI5: J75.4, J76.8, U23.10, U24.3
unnamed: D6.C, R10.2
unnamed: D1.C, R7.2
unnamed: D2.A, R3.1
unnamed: C5.1, U3.17, Y2.3
unnamed: J1.D+, R11.2
unnamed: C7.1, U3.16, Y2.1
unnamed: J14.D-, R15.2
unnamed: D4.C, R9.2
unnamed: F1.2, J9.2, S1.1
unnamed: J14.D+, R14.2
unnamed: R5.1, U1.5
unnamed: F2.2, J17.2, S2.1
unnamed: R17.1, U4.5
unnamed: D5.C, R20.2
unnamed: LED2.A, R16.1
unnamed: D7.C, R8.2
unnamed: D3.C, R19.2
unnamed: D8.A, R23.1
unnamed: C17.1, U7.17, Y1.3
unnamed: J1.D-, R12.2
unnamed: C18.1, U7.16, Y1.1
unnamed: J27.D-, R27.2
unnamed: J27.D+, R26.2
unnamed: F3.2, J30.2, S5.1
unnamed: R29.1, U9.5
unnamed: D10.C, R32.2
unnamed: LED3.A, R28.1
unnamed: D11.C, R25.2
unnamed: D9.C, R31.2
unnamed: D12.A, R35.1
unnamed: C27.1, U11.17, Y3.3
unnamed: C28.1, U11.16, Y3.1
unnamed: J40.D-, R39.2
unnamed: J40.D+, R38.2
unnamed: F4.2, J43.2, S7.1
unnamed: R41.1, U13.5
unnamed: D14.C, R44.2
unnamed: LED1.A, R13.1
unnamed: LED4.A, R40.1
unnamed: D15.C, R37.2
unnamed: D13.C, R43.2
unnamed: D16.A, R47.1
unnamed: C37.1, U15.17, Y4.3
unnamed: C38.1, U15.16, Y4.1
unnamed: J53.D-, R51.2
unnamed: J53.D+, R50.2
unnamed: F5.2, J56.2, S9.1
unnamed: R53.1, U17.5
unnamed: D18.C, R56.2
unnamed: LED5.A, R52.1
unnamed: D19.C, R49.2
unnamed: D17.C, R55.2
unnamed: D20.A, R59.1
unnamed: C47.1, U19.17, Y5.3
unnamed: C48.1, U19.16, Y5.1
unnamed: J66.D-, R63.2
unnamed: J66.D+, R62.2
unnamed: F6.2, J69.2, S11.1
unnamed: R65.1, U21.5
unnamed: D22.C, R68.2
unnamed: LED6.A, R64.1
unnamed: D23.C, R61.2
unnamed: D21.C, R67.2
unnamed: D24.A, R71.1
unnamed: C57.1, U23.17, Y6.3
unnamed: C58.1, U23.16, Y6.1
RAW: J3.1, J9.1, S1.2, SJ2.1, U6.1, U6.3
RAW1: J17.1, J18.1, S2.2, SJ1.1, U5.1, U5.3
RAW2: J30.1, J31.1, S5.2, SJ3.1, U10.1, U10.3
RAW3: J43.1, J44.1, S7.2, SJ4.1, U14.1, U14.3
RAW4: J56.1, J57.1, S9.2, SJ5.1, U18.1, U18.3
RAW5: J69.1, J70.1, S11.2, SJ6.1, U22.1, U22.3
RFM_INT: U2.14, U3.1
RFM_INT1: U7.1, U8.14
RFM_INT2: U11.1, U12.14
RFM_INT3: U15.1, U16.14
RFM_INT4: U19.1, U20.14
RFM_INT5: U23.1, U24.14
RFM_IO1: JP1.1, U2.15
RFM_IO2: JP2.1, U2.16
RFM_IO3: JP3.1, U8.15
RFM_IO4: JP4.1, U8.16
RFM_IO5: JP5.1, U12.15
RFM_IO6: JP6.1, U12.16
RFM_IO7: JP7.1, U16.15
RFM_IO8: JP8.1, U16.16
RFM_IO9: JP9.1, U20.15
RFM_IO10: JP10.1, U20.16
RFM_IO11: JP11.1, U24.15
RFM_IO12: JP12.1, U24.16
RFM_RST: U2.6, U3.25
RFM_RST1: U7.25, U8.6
RFM_RST2: U11.25, U12.6
RFM_RST3: U15.25, U16.6
RFM_RST4: U19.25, U20.6
RFM_RST5: U23.25, U24.6
RXI: J3.10, U3.20
RXI1: J18.10, U7.20
RXI2: J31.10, U11.20
RXI3: J44.10, U15.20
RXI4: J57.10, U19.20
RXI5: J70.10, U23.20
RXLED: R10.1, U3.8
RXLED1: R8.1, U7.8
RXLED2: R25.1, U11.8
RXLED3: R37.1, U15.8
RXLED4: R49.1, U19.8
RXLED5: R61.1, U23.8
SCK: J10.3, J11.9, U2.4, U3.9
SCK1: J23.3, J24.9, U7.9, U8.4
SCK2: J36.3, J37.9, U11.9, U12.4
SCK3: J49.3, J50.9, U15.9, U16.4
SCK4: J62.3, J63.9, U19.9, U20.4
SCK5: J75.3, J76.9, U23.9, U24.4
SCL: J2.4, U3.18
SCL1: J22.4, U7.18
SCL2: J35.4, U11.18
SCL3: J48.4, U15.18
SCL4: J61.4, U19.18
SCL5: J74.4, U23.18
SDA: J2.3, U3.19
SDA1: J22.3, U7.19
SDA2: J35.3, U11.19
SDA3: J48.3, U15.19
SDA4: J61.3, U19.19
SDA5: J74.3, U23.19
SHLD: J1.SHIELD, J1.SHIELD2, J1.SHIELD3, J1.SHIELD4, J1.SHIELD5, J1.SHIELD6, J1.SHIELD7, J1.SHIELD8, J1.SHIELD9, J1.SHIELD10
SHLD1: J14.SHIELD, J14.SHIELD2, J14.SHIELD3, J14.SHIELD4, J14.SHIELD5, J14.SHIELD6, J14.SHIELD7, J14.SHIELD8, J14.SHIELD9, J14.SHIELD10
SHLD2: J27.SHIELD, J27.SHIELD2, J27.SHIELD3, J27.SHIELD4, J27.SHIELD5, J27.SHIELD6, J27.SHIELD7, J27.SHIELD8, J27.SHIELD9, J27.SHIELD10
SHLD3: J40.SHIELD, J40.SHIELD2, J40.SHIELD3, J40.SHIELD4, J40.SHIELD5, J40.SHIELD6, J40.SHIELD7, J40.SHIELD8, J40.SHIELD9, J40.SHIELD10
SHLD4: J53.SHIELD, J53.SHIELD2, J53.SHIELD3, J53.SHIELD4, J53.SHIELD5, J53.SHIELD6, J53.SHIELD7, J53.SHIELD8, J53.SHIELD9, J53.SHIELD10
SHLD5: J66.SHIELD, J66.SHIELD2, J66.SHIELD3, J66.SHIELD4, J66.SHIELD5, J66.SHIELD6, J66.SHIELD7, J66.SHIELD8, J66.SHIELD9, J66.SHIELD10
STAT: R3.2, U3.32
STAT1: R23.2, U7.32
STAT2: R35.2, U11.32
STAT3: R47.2, U15.32
STAT4: R59.2, U19.32
STAT5: R71.2, U23.32
TXLED: R7.1, U3.22
TXLED1: R19.1, U7.22
TXLED2: R31.1, U11.22
TXLED3: R43.1, U15.22
TXLED4: R55.1, U19.22
TXLED5: R67.1, U23.22
TXO: J3.9, U3.21
TXO1: J18.9, U7.21
TXO2: J31.9, U11.21
TXO3: J44.9, U15.21
TXO4: J57.9, U19.21
TXO5: J70.9, U23.21
UCAP: C8.2, U3.6
UCAP1: C19.2, U7.6
UCAP2: C29.2, U11.6
UCAP3: C39.2, U15.6
UCAP4: C49.2, U19.6
UCAP5: C59.2, U23.6
USB_VCC: C9.1, C11.2, D4.A, J1.VBUS, J8.2, SJ2.2, U1.4, U3.2, U3.7
USB_VCC1: C3.2, C20.1, D5.A, J14.VBUS, J16.2, SJ1.2, U4.4, U7.2, U7.7
USB_VCC2: C22.2, C30.1, D10.A, J27.VBUS, J29.2, SJ3.2, U9.4, U11.2, U11.7
USB_VCC3: C32.2, C40.1, D14.A, J40.VBUS, J42.2, SJ4.2, U13.4, U15.2, U15.7
USB_VCC4: C42.2, C50.1, D18.A, J53.VBUS, J55.2, SJ5.2, U17.4, U19.2, U19.7
USB_VCC5: C52.2, C60.1, D22.A, J66.VBUS, J68.2, SJ6.2, U21.4, U23.2, U23.7
VBATT: C1.+, F1.1, J7.2, J12.2, R1.2, U1.3
VBATT1: C2.+, F2.1, J15.2, J21.2, R21.2, U4.3
VBATT2: C21.+, F3.1, J28.2, J34.2, R33.2, U9.3
VBATT3: C31.+, F4.1, J41.2, J47.2, R45.2, U13.3
VBATT4: C41.+, F5.1, J54.2, J60.2, R57.2, U17.3
VBATT5: C51.+, F6.1, J67.2, J73.2, R69.2, U21.3
VBATT_LVL: R1.1, R2.2, U3.26
VBATT_LVL1: R21.1, R22.2, U7.26
VBATT_LVL2: R33.1, R34.2, U11.26
VBATT_LVL3: R45.1, R46.2, U15.26
VBATT_LVL4: R57.1, R58.2, U19.26
VBATT_LVL5: R69.1, R70.2, U23.26

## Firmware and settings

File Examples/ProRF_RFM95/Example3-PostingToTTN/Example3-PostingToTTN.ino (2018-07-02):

/*
 
  This example is heavily based on the 'ttn-abp' example by Thomas Telkamp and Matthijs Kooijman

  This example sends a valid LoRaWAN packet with payload "Hello,
  world!", using frequency and encryption settings matching those of
  the The Things Network.
 
  This uses ABP (Activation-by-personalisation), where a DevAddr and
  Session keys are preconfigured (unlike OTAA, where a DevEUI and
  application key is configured, while the DevAddr and session keys are
  assigned/generated in the over-the-air-activation procedure).
 
  Note: LoRaWAN per sub-band duty-cycle limitation is enforced (1% in
  g1, 0.1% in g2), but not the TTN fair usage policy (which is probably
  violated by this sketch when left running for longer)!
 
  To use this sketch, first register your application and device with
  the things network, to set or generate a DevAddr, NwkSKey and
  AppSKey. Each device should have their own unique values for these
  fields.
 
  Do not forget to define the radio type correctly in config.h.
 
 */

#include <lmic.h> //Click here to get the library: http://librarymanager/All#IBM_LMIC
#include <hal/hal.h>
#include <SPI.h>

// LoRaWAN Network Session Key
// Get this by registering a new device on TTN, using the ABP (Activation By Personalization) method (not Over The Air)
static const PROGMEM u1_t NWKSKEY[16] = { 0x2C, 0x02, 0x90, 0x00, 0xA7, 0x29, 0x48, 0x86, 0xB1, 0xAD, 0xDA, 0x0E, 0x05, 0xD6, 0x05, 0xF0 };

// LoRaWAN Application Session Key
// Get this by registering a new device from the TTN (The Things Network) console
static const u1_t PROGMEM APPSKEY[16] = { 0x17, 0x41, 0xA6, 0xC4, 0x95, 0xC5, 0xEB, 0xAA, 0x41, 0xAA, 0x69, 0x9E, 0x6E, 0x80, 0xA4, 0x91 };

// LoRaWAN Device Address
// Get this by registering a new device from TTN
static const u4_t DEVADDR = 0x2601131C;

// These callbacks are only used in over-the-air activation, so they are
// left empty here (we cannot leave them out completely unless
// DISABLE_JOIN is set in config.h, otherwise the linker will complain).
void os_getArtEui (u1_t* buf) { }
void os_getDevEui (u1_t* buf) { }
void os_getDevKey (u1_t* buf) { }

static uint8_t mydata[] = "Hello, world!";
static osjob_t sendjob;

// Schedule TX every this many seconds (might become longer due to duty cycle limitations).
const unsigned TX_INTERVAL = 60;

//Pin mapping
//On the SparkFun ProRF NSS (aka !CS) is A5, DIO is 7, 10, 11
//NOTE: You must close the 'LoRa WAN' jumpers on the back of the ProRF. This will connect D10 and D11 to the DIO pins on the RFM95 module
const lmic_pinmap lmic_pins = {
    .nss = A5,
    .rxtx = LMIC_UNUSED_PIN,
    .rst = 4,
    .dio = {7, 10, 11},
};

void onEvent (ev_t ev) {
    Serial.print(os_getTime());
    Serial.print(": ");
    switch(ev) {
        case EV_SCAN_TIMEOUT:
            Serial.println(F("EV_SCAN_TIMEOUT"));
            break;
        case EV_BEACON_FOUND:
            Serial.println(F("EV_BEACON_FOUND"));
            break;
        case EV_BEACON_MISSED:
            Serial.println(F("EV_BEACON_MISSED"));
            break;
        case EV_BEACON_TRACKED:
            Serial.println(F("EV_BEACON_TRACKED"));
            break;
        case EV_JOINING:
            Serial.println(F("EV_JOINING"));
            break;
        case EV_JOINED:
            Serial.println(F("EV_JOINED"));
            break;
        case EV_RFU1:
            Serial.println(F("EV_RFU1"));
            break;
        case EV_JOIN_FAILED:
            Serial.println(F("EV_JOIN_FAILED"));
            break;
        case EV_REJOIN_FAILED:
            Serial.println(F("EV_REJOIN_FAILED"));
            break;
        case EV_TXCOMPLETE:
            Serial.println(F("EV_TXCOMPLETE (includes waiting for RX windows)"));
            if (LMIC.txrxFlags & TXRX_ACK)
              Serial.println(F("Received ack"));
            if (LMIC.dataLen) {
              Serial.println(F("Received "));
              Serial.println(LMIC.dataLen);
              Serial.println(F(" bytes of payload"));
            }
            // Schedule next transmission
            os_setTimedCallback(&sendjob, os_getTime()+sec2osticks(TX_INTERVAL), do_send);
            break;
        case EV_LOST_TSYNC:
            Serial.println(F("EV_LOST_TSYNC"));
            break;
        case EV_RESET:
            Serial.println(F("EV_RESET"));
            break;
        case EV_RXCOMPLETE:
            // data received in ping slot
            Serial.println(F("EV_RXCOMPLETE"));
            break;
        case EV_LINK_DEAD:
            Serial.println(F("EV_LINK_DEAD"));
            break;
        case EV_LINK_ALIVE:
            Serial.println(F("EV_LINK_ALIVE"));
            break;
         default:
            Serial.println(F("Unknown event"));
            break;
    }
}

void do_send(osjob_t* j){
    // Check if there is not a current TX/RX job running
    if (LMIC.opmode & OP_TXRXPEND) {
        Serial.println(F("OP_TXRXPEND, not sending"));
    } else {
        // Prepare upstream data transmission at the next possible time.
        LMIC_setTxData2(1, mydata, sizeof(mydata)-1, 0);
        Serial.println(F("Packet queued"));
    }
    // Next TX is scheduled after TX_COMPLETE event.
}

void setup() {
    Serial.begin(115200);
    Serial.println(F("Starting"));
    
    os_init(); // LMIC init
    
    LMIC_reset(); // Reset the MAC state. Session and pending data transfers will be discarded.

    // Set static session parameters. Instead of dynamically establishing a session
    // by joining the network, precomputed session parameters are be provided.
    #ifdef PROGMEM
    // On AVR, these values are stored in flash and only copied to RAM
    // once. Copy them to a temporary buffer here, LMIC_setSession will
    // copy them into a buffer of its own again.
    uint8_t appskey[sizeof(APPSKEY)];
    uint8_t nwkskey[sizeof(NWKSKEY)];
    memcpy_P(appskey, APPSKEY, sizeof(APPSKEY));
    memcpy_P(nwkskey, NWKSKEY, sizeof(NWKSKEY));
    LMIC_setSession (0x1, DEVADDR, nwkskey, appskey);
    #else
    // If not running an AVR with PROGMEM, just use the arrays directly
    LMIC_setSession (0x1, DEVADDR, NWKSKEY, APPSKEY);
    #endif

    // NA-US channels 0-71 are configured automatically
    // but only one group of 8 (a subband) should be active
    // TTN recommends the second sub band, 1 in a zero based count.
    // https://github.com/TheThingsNetwork/gateway-conf/blob/master/US-global_conf.json
    LMIC_selectSubBand(1);

    // Disable link check validation
    LMIC_setLinkCheckMode(0);

    // TTN uses SF9 for its RX2 window.
    LMIC.dn2Dr = DR_SF9;

    // Set data rate and transmit power for uplink (note: txpow seems to be ignored by the library)
    LMIC_setDrTxpow(DR_SF7, 14);

    // Start job
    do_send(&sendjob);
}

void loop() {
    os_runloop_once();
}

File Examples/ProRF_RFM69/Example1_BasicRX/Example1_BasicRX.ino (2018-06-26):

/*
  ProRF - Basic data transmission over the air
  By: Nathan Seidle
  SparkFun Electronics
  Date: June 12th, 2018
  License: This code is public domain but you buy me a beer if you use this and we meet someday (Beerware License).

  This example shows how to transmit a simple data message from the TX (transmitter) to the RX (receiver).
  Data can be sent in either direction but these example use TX and RX nomenclature to avoid confusion.

  The status LED turns on if a packet is successfully received. Helpful for range testing.

  This code is written for the receiver or 'server' that listens for incoming data and responds with a
  'I heard you' packet.

  This code is heavily based on RadioHead's rfm_client and rfm_server examples.

  Feel like supporting open source hardware?
  Buy a board from SparkFun! 
  ProRF with RFM69: https://www.sparkfun.com/products/14757
  ProRF LoRa with RFM95: https://www.sparkfun.com/products/14785

  Software and Hardware Setup:
  You'll need to download and install the SparkFun Atmel Boards. See this repo:
  https://github.com/sparkfun/Arduino_Boards for more information.
  Select 'SparkFun Pro Micro, 3.3V' as your Tools->Board.
  Both the TX and RX ProRF boards will need a wire antenna. We recommend a 3" piece of wire.
*/

#include <SPI.h>

//Install this library by downloading the lastest zip from http://www.airspayce.com/mikem/arduino/RadioHead/
#include <RH_RF69.h>

//On the SparkFun ProRF the RFM CS pin is connected to pin A5, the RFM interrupt is on pin 7
RH_RF69 rf69(A5, 7);

const byte LED = 13; //Status LED is on pin 13

int packetCounter = 0; //Counts the number of packets sent

long timeSinceLastPacket = 0; //Tracks the time stamp of last packet received

void setup()
{
  pinMode(LED, OUTPUT);
  digitalWrite(LED, LOW);

  Serial.begin(9600);
  //while (Serial == false) ; //This line requires USB to be hooked up. If you're going to do battery powered range testing, comment it out.

  Serial.println("RFM Test");

  if (rf69.init() == false)
  {
    Serial.println("Radio Init Failed - Freezing");
    while (1);
  }

  //The SparkFun ProRF uses the RFM69HCW-915S2
  //This is a highpower, 915MHz device. The 915MHz ISM band is centered
  //around 915MHz but ranges from 902 to 928MHz so if needed you could use
  //908.2 for example if the band is very busy.
  rf69.setFrequency(921.2);

  //Europe is 863-870 with center at 868MHz
  //This works but it is unknown how well the radio configures to this frequency
  //rf69.setFrequency(864.1);

  //Set power to 14dBm. Can also go to higher 20dBm if needed.
  //rf69.setTxPower(14, true);
  rf69.setTxPower(20, true);

  //The encryption key has to be the same as the one in the transmitter
  uint8_t key[] = {"AbraRabbit123456"}; //This works but the key must be 16 characters long
  //  uint8_t key[] = { 0x01, 0x02, 0x03, 0x04, 0x05, 0x06, 0x07, 0x08,
  //                    0x01, 0x02, 0x03, 0x04, 0x05, 0x06, 0x07, 0x08
  //                  }; //This also works
  rf69.setEncryptionKey(key);
}

void loop()
{
  if (rf69.available())
  {
    // Should be a message for us now
    uint8_t buf[RH_RF69_MAX_MESSAGE_LEN];
    uint8_t len = sizeof(buf);
    if (rf69.recv(buf, &len))
    {
      digitalWrite(LED, HIGH); //Turn on status LED
      timeSinceLastPacket = millis(); //Timestamp this packet

      Serial.print("Got message: ");
      Serial.print((char*)buf);
      Serial.print(" RSSI: ");
      Serial.print(rf69.lastRssi(), DEC);
      Serial.println();

      // Send a reply
      char toSend[50];
      sprintf(toSend, "And hello back. Counter: %d", packetCounter++);
      rf69.send(toSend, sizeof(toSend));

      rf69.waitPacketSent();
      Serial.println("Sent a reply");
    }
    else
    {
      Serial.println("Recieve failed");
    }
  }

  //Turn off status LED if we haven't received a packet after 1s
  if(millis() - timeSinceLastPacket > 1000)
  {
    digitalWrite(LED, LOW); //Turn off status LED
    timeSinceLastPacket = millis(); //Don't write LED but every 1s
  }
}

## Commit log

2018-05-25 Adding prod IDs. This changed some FPs so fixed routes. Moved Int Pin to avoid I2C
    [Pro_RF.brd, Pro_RF.sch]
2018-06-01 Many updates. v02.
    [Pro_RF-Panel.GBL, Pro_RF-Panel.GBO, Pro_RF-Panel.GBP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]
2018-06-11 Adding pullup to CS
    [Pro_RF.brd, Pro_RF.sch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]
2018-06-26 Adding Examples
    [Pro_RF-Panel.GBL, Pro_RF-Panel.GBO, Pro_RF-Panel.GBP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]
2018-07-30 updating to sparkfun silk
    [Pro_RF.brd, Pro_RF.sch]
2018-08-06 Clean up
    [Pro_RF.brd, Pro_RF.sch]
2018-11-26 added production folder
    added a production folder for the boards that were just ordered
    [Pro_RF-Panel.GBL, Pro_RF-Panel.GBO, Pro_RF-Panel.GBP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]

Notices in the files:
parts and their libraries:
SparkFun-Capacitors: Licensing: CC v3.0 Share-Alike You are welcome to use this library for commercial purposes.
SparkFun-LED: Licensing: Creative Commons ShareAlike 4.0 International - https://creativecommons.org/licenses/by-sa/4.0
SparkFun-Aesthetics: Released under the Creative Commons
